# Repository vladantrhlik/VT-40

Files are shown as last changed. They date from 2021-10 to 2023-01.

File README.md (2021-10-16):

# VT-40
40% ortholinear mechanical keyboard

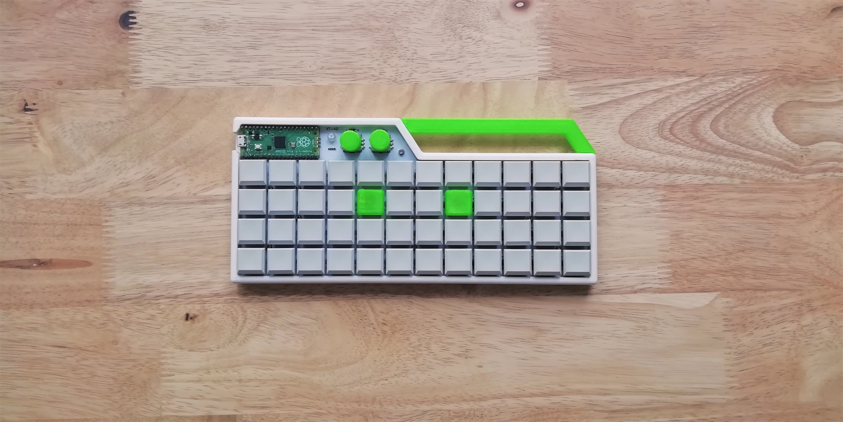
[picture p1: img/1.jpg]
vt-40


## Build info
PCB has Planck MIT layout and supports two rotary encoders and 2 RGB LEDs (which sadly don't work, because I'm bad at soldering xD). For switches I chose Kailh choc reds (lubed with 205g0), because I wanted to try low profile switches for a while. Case is 3D printed as well as F and J keycaps and knobs for rotary encoders. I also added a little buzzer to the bottom and modified KMK firmware to make it work, which was suprisingly pretty easy.

## KMK
[KMK firmware](https://github.com/KMKfw) is awesome. Since it’s based on circuitpython, you don’t need to install anything on your computer. You just plug it in, keyboard shows up as USB drive and you can edit python files which are stored there. It also has many features as QMK (RGB, BLE, split keyboards).
### Pinout
Key matrix:
```py
keyboard.col_pins = (board.GP6,board.GP7,board.GP8,board.GP9,board.GP10,board.GP11,board.GP12,board.GP13,board.GP21,board.GP20,board.GP19,board.GP18,board.GP22)
keyboard.row_pins = (board.GP2,board.GP3,board.GP4,board.GP5)
keyboard.diode_orientation = DiodeOrientation.COLUMNS
```
Encoders:
```py
encoder_map = [
    [
        (KC.VOLD,KC.VOLU,1),
        (KC.A,KC.B,1),
    ],
]
encoder_ext = EncoderHandler([board.GP26, board.GP16],[board.GP27, board.GP17], encoder_map)
```
My default layer:
```py
keyboard.keymap = [
	[
		KC.ESC,  KC.Q,    KC.W,  KC.E,   KC.R,  KC.T,   KC.Y,   KC.U,    KC.I,     KC.O,    KC.P,    KC.BSPC,  KC.MPLY,
		KC.TAB,  KC.A,    KC.S,  KC.D,   KC.F,  KC.G,   KC.H,   KC.J,    KC.K,     KC.L,    KC.GRV,  KC.LSFT(KC.BSLS),  KC.MUTE,
		KC.LSFT, KC.Z,    KC.X,  KC.C,   KC.V,  KC.B,   KC.N,   KC.M,    KC.COMMA, KC.DOT,  KC.UP,   KC.ENT,   XXXXXXX,
		KC.LCTL, KC.LALT, KC.MO(1),   KC.SPC, KC.MO(2), KC.SPC, KC.SPC, KC.RALT, KC.NO,    KC.LEFT, KC.DOWN, KC.RIGHT, XXXXXXX,
	],
 ...
]
```
Encoders buttons are wired to 13. column of key matrix, so you can change their behaviour on different layers.

## PCB
PCB supports CHOC, MX and ALPS switches. There are also 2 rotary encoders (EC11) and pads for two [TH WS2811 LEDs](https://www.aliexpress.com/item/32825363423.html?spm=a2g0s.9042311.0.0.47844c4dhfjDqT).

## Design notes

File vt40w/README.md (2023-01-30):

# VT-40w
Modified version of VT-40 PCB with IO expander and XIAO BLE microcontroller.

## Build
For a long time a wanted to build a wireless keyboard, and because I had few of the VT-40 PCBs laying around, I decided to modify it to work with a BLE capable microcroller.
For the microcontroller I chode XIAO BLE, which is new cheap uC with nrf52840. The only problem was that it only has 11 GPIOs and you need at least 16 GPIOs for Planck layout.
I decided to use IO expander MCP23017 which has 16 GPIOs and can communicate with uC via I2C.

I decided to make a small PCB for MCP23017 which would fit into space where RPi Pico is supposed to be. I also made a PCB for uC with pinheader for connecting IO Expaner and other periferals.

For the build I used KTT Seasalt Lemons lubed with Krytox 205g0. They are mounted on 2.5mm plate printed from black PLA and there's also foam between pcb and plate for better sound.

### Case design
Case was designed in Autodesk Inventor and is made out of 5 parts - 3 for the main frame, bottom with slight angle and top to cover all the electronics. 
The PCB is mounted with a little slides inside the main frame, so no screws are needed.

#### Randomly Generated pattern in Blender for bottom part
I decided to make bottom part i bit more interesting, so I generated random pattern of rectangles in Blender, and then imported it to Inventor.

<p align="center">
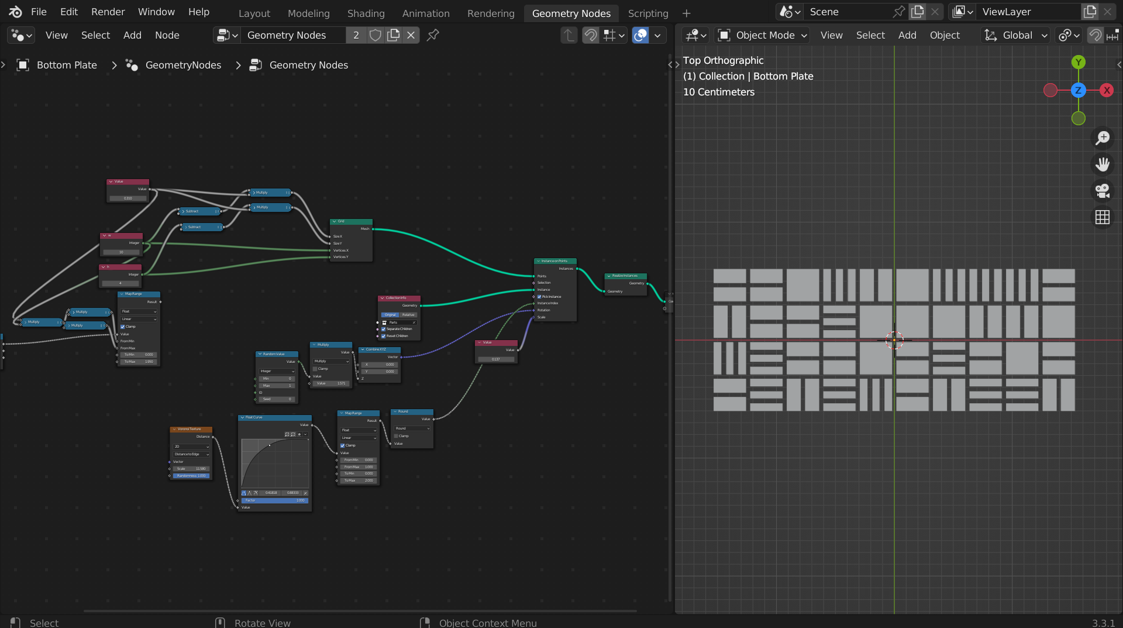
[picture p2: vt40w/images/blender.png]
Light
  
&nbsp; &nbsp; &nbsp; &nbsp;
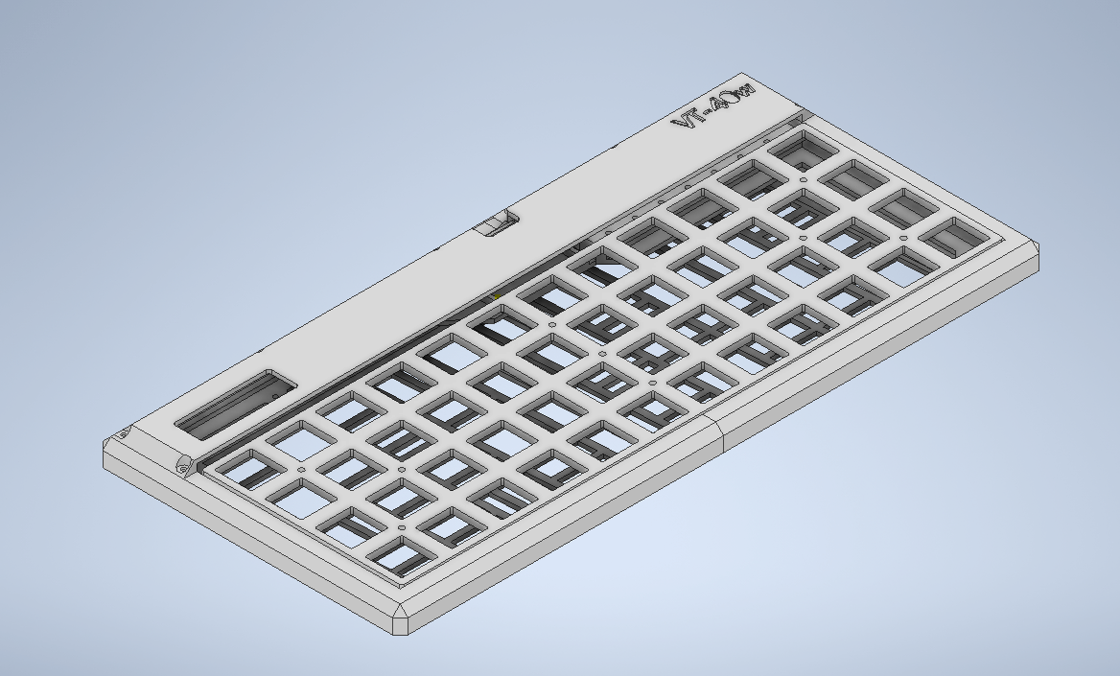
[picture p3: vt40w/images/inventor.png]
Dark
  
</p>

### Firmware
At first I wanted to try ZMK firmware, but because I could get the matrix working I decided to use KMK firmware. I also wrote a custom scanner for MCP23017.

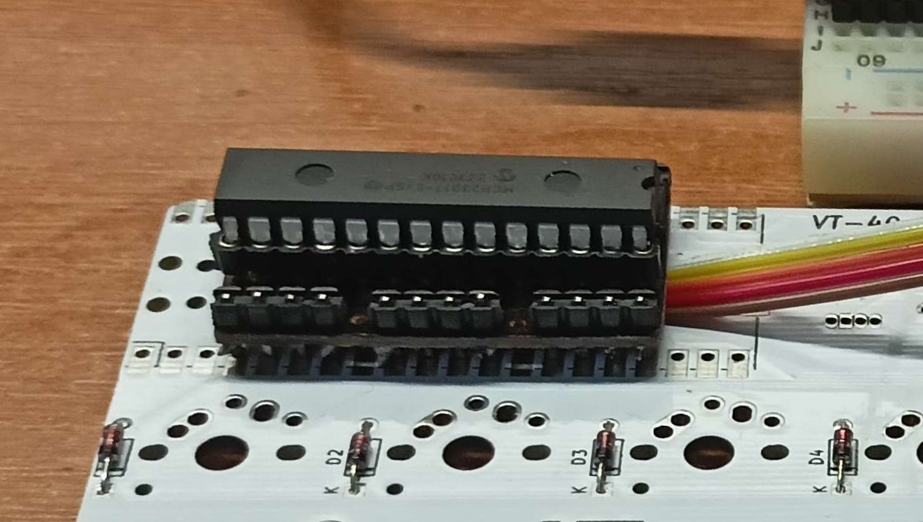
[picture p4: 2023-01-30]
vt40w/images/IMG20221226110710_crop.jpg

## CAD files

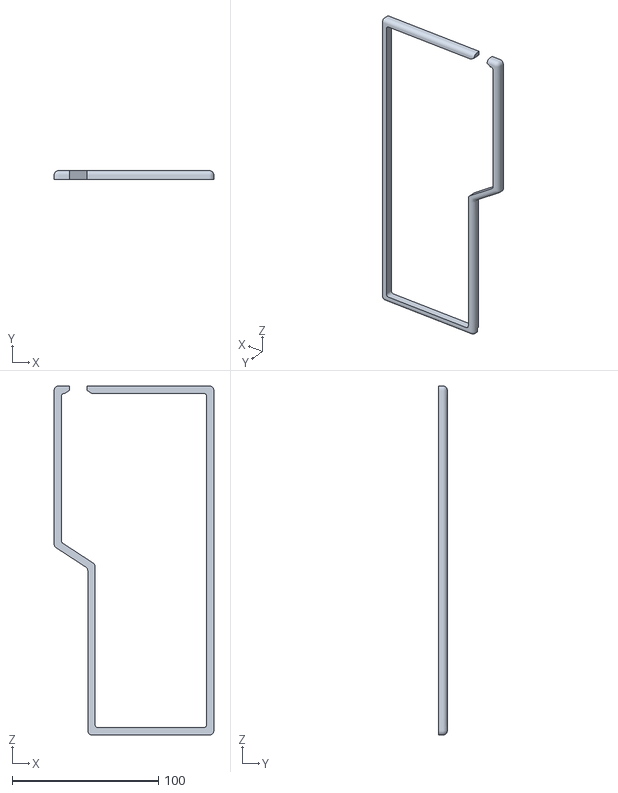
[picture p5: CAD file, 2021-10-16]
stl/top.stl
109.2 x 6.00 x 238.6

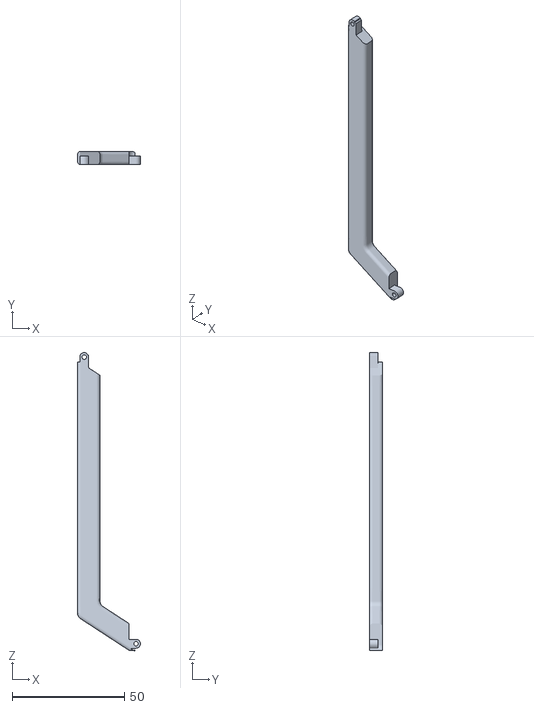
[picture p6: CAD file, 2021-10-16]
stl/handle.stl
28.0 x 6.00 x 132.5

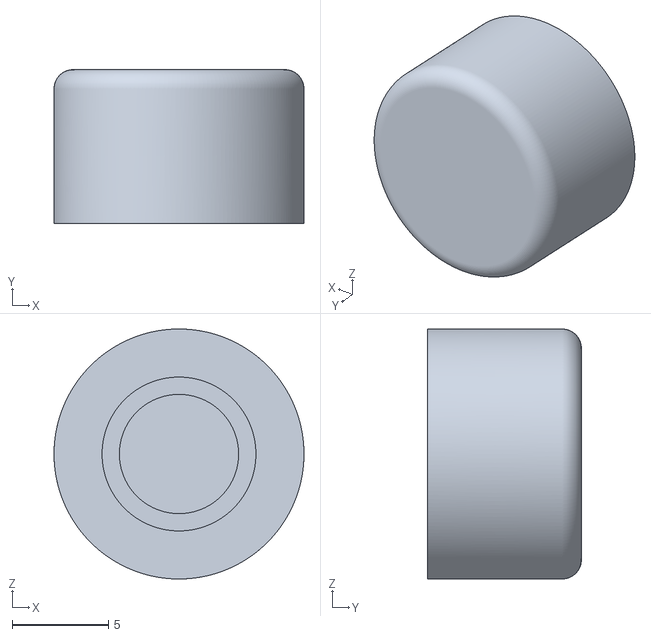
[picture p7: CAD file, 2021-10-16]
stl/knob.stl
13.0 x 8.00 x 13.0

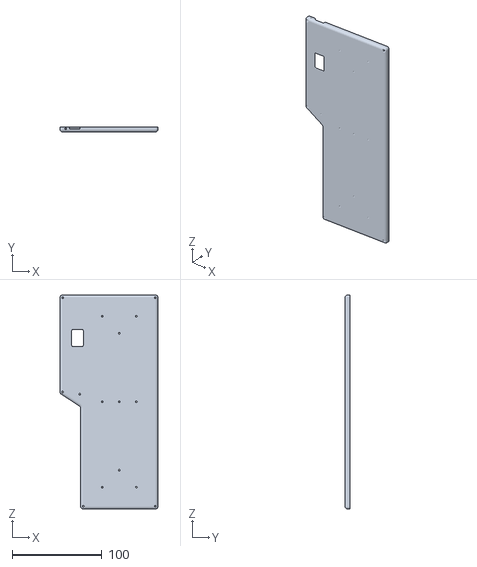
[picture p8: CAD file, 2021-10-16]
stl/bottom.stl
109.2 x 5.50 x 238.6
